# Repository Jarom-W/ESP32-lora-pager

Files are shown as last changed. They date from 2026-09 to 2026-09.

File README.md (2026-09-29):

# ESP32-lora-pager
Source code and supporting files for the ESP32 LoRa powered paging device

LoRa_Enclosure_Design_Pack_Prototype -> The 3D printed prototype case and all related files.

firmware.ino -> Source code firmware written in the Arduino IDE

pager.kicad_pcb -> KiCad PCB file

pager.kicad_pro -> KiCad Project file

pager.kicad_sch -> KiCad PCB schematic

pager_rev1_gerbers.zip -> Gerbers for ordering PCB from a factory

print.pdf -> Printed render of the final PCB.

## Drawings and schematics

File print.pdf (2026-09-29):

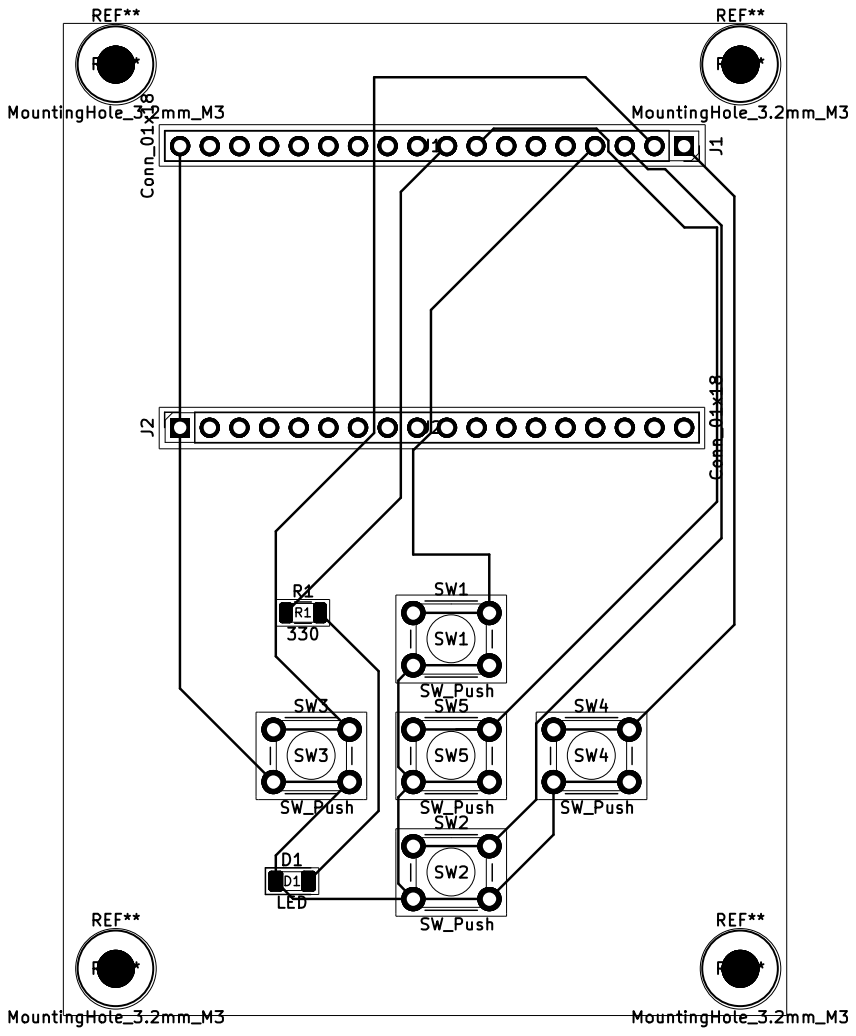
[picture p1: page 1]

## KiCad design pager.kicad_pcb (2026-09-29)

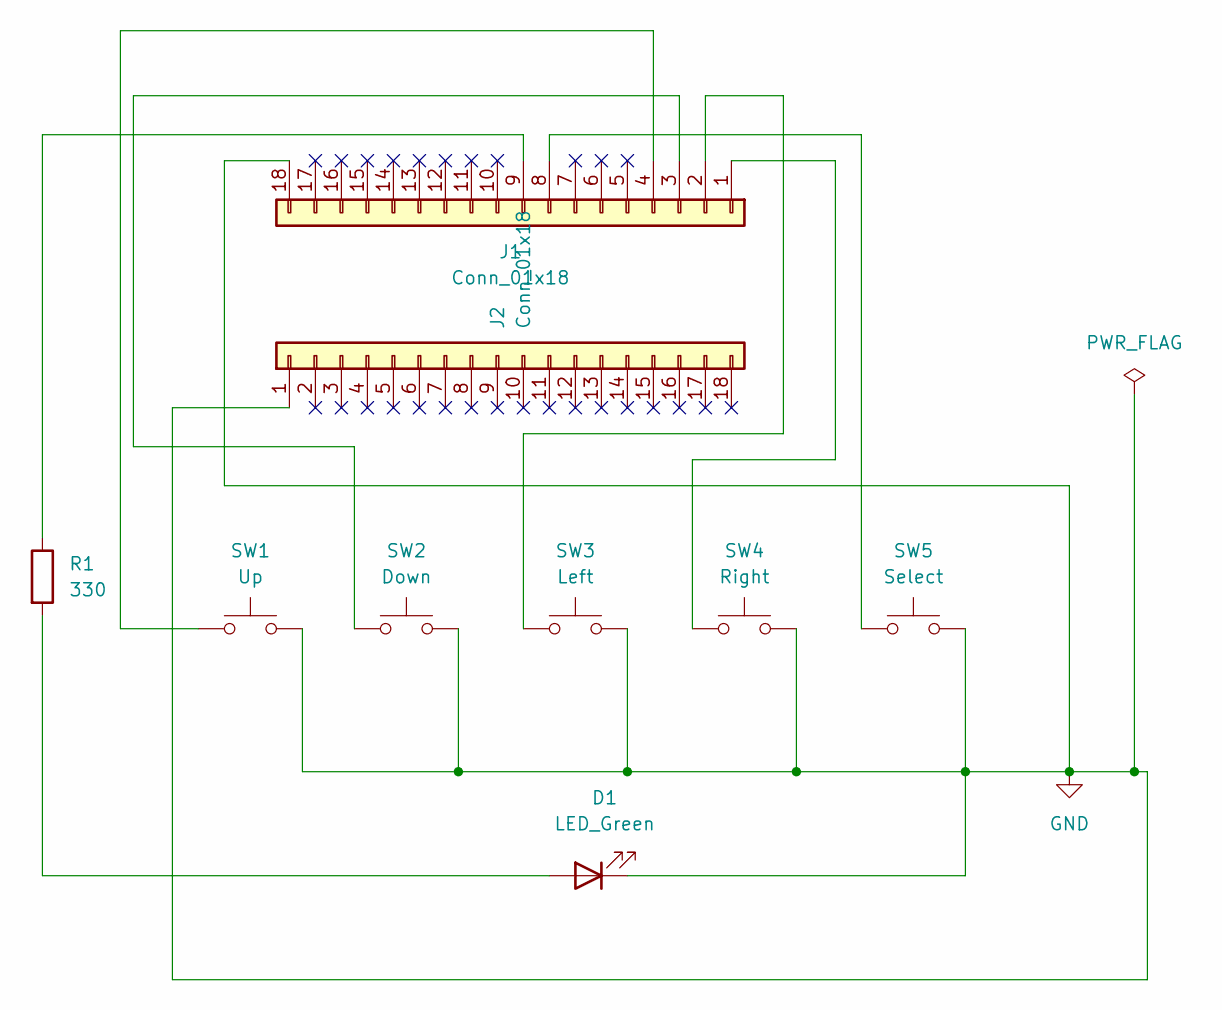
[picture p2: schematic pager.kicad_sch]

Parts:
D1: LED_Green; LED_D5.0mm
J1, J2: Conn_01x18; PinSocket_1x18_P2.54mm_Vertical
R1: 330; R_Axial_DIN0207_L6.3mm_D2.5mm_P7.62mm_Horizontal
SW1: Up; SW_PUSH_6mm
SW2: Down; SW_PUSH_6mm
SW3: Left; SW_PUSH_6mm
SW4: Right; SW_PUSH_6mm
SW5: Select; SW_PUSH_6mm

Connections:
GND: D1.1 (K), J1.18, J2.1, SW1.2, SW2.2, SW3.2, SW4.2, SW5.2
unnamed: D1.2 (A), R1.2
unnamed: J1.1, SW4.1
unnamed: J1.2, SW3.1
unnamed: J1.3, SW2.1
unnamed: J1.4, SW1.1
unnamed: J1.8, SW5.1
unnamed: J1.9, R1.1

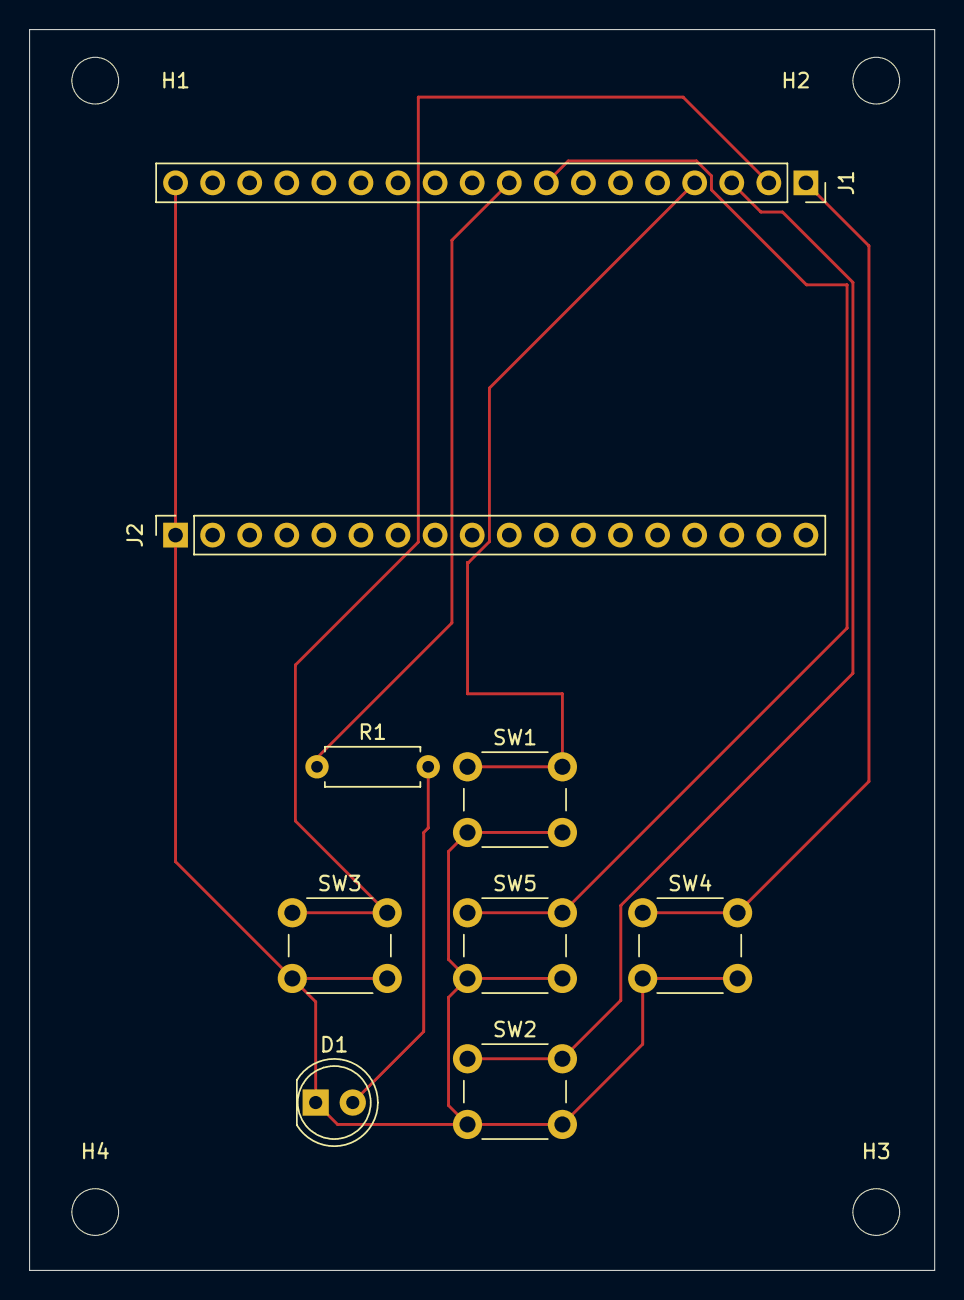
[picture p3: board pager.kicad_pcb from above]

Board: 2 copper layers, 62.0 x 85.0 mm, 13 parts (0 on the bottom side), 8 nets.

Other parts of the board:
H1, H2, H3, H4: MountingHole_3.2mm_M3

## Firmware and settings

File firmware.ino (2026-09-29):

/*
  HeltecPager 1.2 - single-file group text pager for Heltec WiFi LoRa 32 V3.
  Flash this SAME sketch onto every device; Settings > Name personalizes it.

  ARDUINO SETUP
    Board package: esp32 by Espressif Systems
    Board: Heltec WiFi LoRa 32(V3) (ESP32-S3, not V2 or V4)
    USB CDC On Boot: Disabled if offered (onboard CP210x USB-UART).
    Core 2.0.17 sets this automatically for the V3; no menu change needed.
    Libraries: RadioLib, Adafruit SSD1306, Adafruit GFX Library
               (accept their dependencies, including Adafruit BusIO)
    Serial Monitor: 115200 baud, Newline

  VALIDATION
    Compiled with esp32 core 2.0.17, RadioLib 7.1.2, Adafruit SSD1306 2.5.17,
    Adafruit GFX Library 1.12.6, Adafruit BusIO 1.17.4.
    Packet parser passed roundtrip, boundary and 100,000 malformed-input tests
    under AddressSanitizer/UndefinedBehaviorSanitizer (leak check disabled).
    Not tested on physical hardware; confirm operation on two boards first.

  EXTERNAL WIRING - GPIO numbers, NOT header positions
    Up -> GPIO4       Down -> GPIO5       Left -> GPIO6
    Right -> GPIO7    Select -> GPIO38
    Each normally-open button connects its GPIO to GND when pressed.
    Internal pull-ups enabled. No button connects to 3.3V or 5V.
    GPIO39 -> 330-ohm resistor -> LED anode (+); LED cathode (-) -> GND.
    Onboard GPIO35 user LED mirrors unread status; orange charge LED untouched.
    Attach the matching antenna before use. Disconnect power while wiring.

  INTERNAL V3 CONNECTIONS (already wired on board)
    OLED: SDA17, SCL18, reset21; Vext36 active LOW
    SX1262: SCK9, MISO11, MOSI10, CS8, DIO1=14, reset12, BUSY13
    TCXO 1.8V, DIO2 RF switch control

  CONTROLS
    Menus: Up/Down selects, Select opens, Left returns.
    Keyboard: arrows move, Select types. '_'=space, '<'=delete, '>'=done.
    Hold Select 700ms to toggle upper/lower case in keyboard.
    Hold Left 700ms to leave keyboard (message draft retained in RAM).
    Send confirmation: Select sends; Left edits.
    Reader: Up/Down scroll; Left returns; Select opens Quick messages.
    Tap Right on Home to open newest unread message.
    New messages open automatically ONLY from Home; remain unread until an
    explicit open/Select. Editing and menu state are never overwritten.

  RADIO / LIMITS
    Direct group broadcast; no mesh, gateway, encryption, authentication or ACK.
    "Transmitted" means local TX completed, NOT delivery confirmed.
    Same channel and firmware required. Names are labels, not trusted identity.
    Max name 12 printable ASCII characters; text 120; inbox holds latest 20.
    Presets: 903/909/915/921/927 MHz; default 915; BW500kHz/SF12/CR4:8,
    20dBm, sync0x12, CRC on, explicit header, 16-symbol preamble.
    Boosted RX gain enabled. All pagers MUST run this radio profile; versions
    1.0/1.1 cannot receive this profile. Existing names/inbox/channel retained.
    Higher power and longer airtime increase energy per message; boosted RX
    also increases listening current. No guaranteed distance multiplier.
    Packet airtime determines TX timeout and busy-channel retry spacing.
    Typical airtime is about 0.5-2 seconds; backoff adds further delay.
    500kHz bandwidth retained for this fixed-channel US-band design; these
    settings alone do not establish FCC compliance. /status shows RF settings
    and the last valid incoming packet RSSI/SNR for manual range tests.
    These are experimental US-band settings, NOT a certification or compliance
    guarantee. Verify your exact board, antenna and permitted operating profile.
    Do not use this build on 433/868-only hardware or outside applicable regions.
    Always-on RX; OLED blanks after 60s. No deep sleep. Not an emergency pager.
    Bounded random backoff + LoRa activity detection; hidden-node losses remain.
    Incoming packets are strictly length/version checked, then deduplicated.
    Inbox is saved to NVS after a 2-second quiet period (recent entries can be
    lost if power is removed immediately). Name/channel saved on explicit change.
    Inbox times are receiver uptime with boot ID; there is no real-time clock.

  BATTERY (Heltec V3.2, standard 4.2V-full single-cell LiPo)
    Built-in divider: GPIO1 ADC, GPIO37 enable HIGH on V3.2.
    Older V3 revisions may require LOW: change BATTERY_ENABLE_LEVEL below.
    No external battery-sense wiring. Home shows icon and estimated percentage;
    Settings > Battery shows voltage. /battery prints diagnostics.
    Samples every 10 seconds, averaging 16 readings and smoothing between reads.
    Sampling pauses during queued/TX activity and for 2 seconds after TX.
    Percentage is a generic voltage estimate, NOT a measured fuel gauge.
    USB/charging changes readings; assess remaining charge with USB unplugged.
    Voltage alone cannot reliably detect charging or battery presence.
    Low warning below 3.50V for 3 samples; re-arms above 3.65V.
    No automatic shutdown; radio continues listening. Capacity (1000mAh, etc.)
    does not change the voltage curve. BATTERY_CALIBRATION can correct readings
    against a multimeter: new factor = old factor * measured / displayed.

  SERIAL COMMANDS (newline terminated)
    /help /battery /status /name Amber /channel 3 /send Hello /inbox /read 1 /demo
    /up /down /left /right /ok /case /back
    /channel uses 1..5; /demo creates a LOCAL simulated incoming message.
    Serial control permits testing before buttons are wired.

  Primary pin reference:
  https://github.com/espressif/arduino-esp32/blob/master/variants/heltec_wifi_lora_32_V3/pins_arduino.h
*/
#include <Arduino.h>
#include <Wire.h>
#include <SPI.h>
#include <Preferences.h>
#include <Adafruit_GFX.h>
#include <Adafruit_SSD1306.h>
#include <RadioLib.h>
#include <esp_system.h>
#include <ctype.h>
#include <stddef.h>

#if !defined(CONFIG_IDF_TARGET_ESP32S3)
#error "Select Heltec WiFi LoRa 32(V3), an ESP32-S3 board."
#endif

constexpr uint8_t PIN_UP=4, PIN_DOWN=5, PIN_LEFT=6, PIN_RIGHT=7, PIN_OK=38;
constexpr uint8_t PIN_ALERT=39, PIN_USER_LED=35;
constexpr uint8_t PIN_OLED_SDA=17, PIN_OLED_SCL=18, PIN_OLED_RST=21, PIN_VEXT=36;
constexpr uint8_t PIN_BATTERY_ADC=1, PIN_BATTERY_ENABLE=37;
constexpr uint8_t BATTERY_ENABLE_LEVEL=HIGH; // V3.2; older V3 may use LOW.
constexpr float BATTERY_DIVIDER=4.9f, BATTERY_CALIBRATION=1.0f;
constexpr uint32_t BATTERY_INTERVAL_MS=10000;
bool batteryValid=false, batterySampling=false, batteryLow=false;
bool batteryWarningPending=false, batteryHasRead=false, batteryTxSeen=false;
float batteryVolts=0.0f, batteryRawVolts=0.0f;
uint8_t batteryPercent=0, batterySamples=0, batteryLowCount=0;
uint32_t batterySumMv=0, batteryLastRead=0, batteryNextSample=0, batteryLastTx=0;

constexpr size_t NAME_MAX_LEN=12, TEXT_MAX_LEN=120, INBOX_MAX=20, HEADER_LEN=22;
constexpr size_t PACKET_MAX=HEADER_LEN+NAME_MAX_LEN+TEXT_MAX_LEN;
// Shared long-range profile. Keep identical on every pager.
constexpr float RADIO_BW_KHZ=500.0f;
constexpr uint8_t RADIO_SF=12, RADIO_CR=8;
constexpr int8_t RADIO_TX_DBM=20;
constexpr uint16_t RADIO_PREAMBLE=16;
constexpr uint32_t SEND_GAP_MS=5000;
uint32_t txTimeoutMs=6000, maxPacketAirMs=2000;
bool haveLinkSample=false;
float lastRxRssi=0.0f, lastRxSnr=0.0f;
uint32_t lastRxAt=0;
constexpr uint8_t CHANNEL_COUNT=5;
const float CHANNEL_MHZ[CHANNEL_COUNT]={903.0f,909.0f,915.0f,921.0f,927.0f};
const char *QUICK[]={"Come here please.","On my way.","Where are you?","I am home.",
                     "Please call me.","Yes.","No.","Thank you!"};
constexpr uint8_t QUICK_COUNT=sizeof(QUICK)/sizeof(QUICK[0]);
const char KEYBOARD[]="ABCDEFGHIJKLMNOPQRSTUVWXYZ0123456789_.<>";
static_assert(sizeof(KEYBOARD)-1 == 40, "Keyboard must contain 40 keys");

Adafruit_SSD1306 oled(128,64,&Wire,-1,100000,100000);
SX1262 radio = new Module(8,14,12,13);
Preferences prefs;
bool prefsReady=false, oledReady=false, oledSleeping=false, radioReady=false;
int16_t lastRadioError=0;
volatile bool radioIRQ=false;
uint64_t deviceId=0;
uint32_t bootId=0, sequenceNumber=0;
char deviceName[NAME_MAX_LEN+1]={0};
uint8_t channelIndex=2;

struct Message {
  uint64_t sender;
  uint32_t senderBoot, sequence, receivedBoot, receivedSeconds;
  int16_t rssi;
  uint8_t unread;
  char name[NAME_MAX_LEN+1];
  char text[TEXT_MAX_LEN+1];
};
// Explicit declarations keep Arduino auto-prototypes after the Message type.
bool decodePacket(const uint8_t *p, size_t len, Message &m);
void acceptMessage(Message &m);

struct InboxStore {
  uint32_t magic;
  uint16_t version, count;
  Message messages[INBOX_MAX];
};
InboxStore inbox={};
bool inboxDirty=false;
uint32_t inboxChangedAt=0;
struct Seen { uint64_t sender; uint32_t boot, sequence; };
Seen seen[64]={};
uint8_t seenNext=0;

// Use int UI state so Arduino's generated function prototypes require no custom types.
enum { HOME, INBOX, READER, EDIT_TEXT, EDIT_NAME, QUICK_MENU, SETTINGS,
       CHANNEL_MENU, CONFIRM_SEND, ABOUT, CLEAR_CONFIRM, BATTERY_VIEW };
enum { UP, DOWN, LEFT, RIGHT, SELECT };
int view=HOME, homeSelection=0, inboxSelection=0, quickSelection=0;
int settingsSelection=0, channelSelection=2, keyboardSelection=0, readerLine=0;
bool lowercase=false;
char draft[TEXT_MAX_LEN+1]={0}, editedName[NAME_MAX_LEN+1]={0};
Message reading={}; // Copy keeps reader stable when a new message shifts inbox.
uint32_t lastInteraction=0, lastDraw=0;
bool drawNeeded=true;
char notice[22]={0};
uint32_t noticeUntil=0;

struct Button {
  explicit Button(uint8_t p) : pin(p) {}
  uint8_t pin;
  bool raw=false, stable=false, held=false;
  uint32_t changed=0, pressed=0;
};
Button buttons[5]={Button(PIN_UP),Button(PIN_DOWN),Button(PIN_LEFT),Button(PIN_RIGHT),Button(PIN_OK)};

uint8_t txBuffer[PACKET_MAX];
size_t txLength=0;
bool txQueued=false, txActive=false;
uint8_t busyAttempts=0;
uint32_t txDue=0, txStarted=0, lastSendAt=0;
bool haveSent=false;
char txText[TEXT_MAX_LEN+1]={0};
char serialLine[180]={0};
size_t serialLength=0;
bool serialOverflow=false;

void IRAM_ATTR onRadioIRQ() { radioIRQ=true; }

void copyText(char *out, size_t size, const char *in) {
  if (!size) return;
  size_t n=strnlen(in,size-1);
  memcpy(out,in,n); out[n]=0;
}
bool printable(const char *s, size_t n) {
  for(size_t i=0;i<n;++i) if((uint8_t)s[i]<32 || (uint8_t)s[i]>126) return false;
  return true;
}
bool hasNonSpace(const char *s) {
  while(*s) { if(*s!=' ') return true; ++s; } return false;
}
void put32(uint8_t *p,uint32_t v) { for(int i=0;i<4;++i) p[i]=(v>>(8*i))&255; }
uint32_t get32(const uint8_t *p) {
  uint32_t v=0; for(int i=0;i<4;++i) v|=((uint32_t)p[i])<<(8*i); return v;
}
void put64(uint8_t *p,uint64_t v) { for(int i=0;i<8;++i) p[i]=(v>>(8*i))&255; }
uint64_t get64(const uint8_t *p) {
  uint64_t v=0; for(int i=0;i<8;++i) v|=((uint64_t)p[i])<<(8*i); return v;
}
size_t makePacket(uint8_t *out,const char *text) {
  size_t nl=strlen(deviceName), tl=strlen(text);
  if(!nl || nl>NAME_MAX_LEN || !tl || tl>TEXT_MAX_LEN) return 0;
  out[0]='P'; out[1]='G'; out[2]=1; out[3]=1;
  put64(out+4,deviceId); put32(out+12,bootId); put32(out+16,++sequenceNumber);
  out[20]=(uint8_t)nl; out[21]=(uint8_t)tl;
  memcpy(out+HEADER_LEN,deviceName,nl); memcpy(out+HEADER_LEN+nl,text,tl);
  return HEADER_LEN+nl+tl;
}
bool decodePacket(const uint8_t *p,size_t len,Message &m) {
  if(len<HEADER_LEN || len>PACKET_MAX) return false;
  if(p[0]!='P' || p[1]!='G' || p[2]!=1 || p[3]!=1) return false;
  size_t nl=p[20],tl=p[21];
  if(!nl || nl>NAME_MAX_LEN || !tl || tl>TEXT_MAX_LEN || len!=HEADER_LEN+nl+tl) return false;
  if(!printable((const char*)p+HEADER_LEN,nl+tl)) return false;
  memset(&m,0,sizeof(m));
  m.sender=get64(p+4); m.senderBoot=get32(p+12); m.sequence=get32(p+16);
  memcpy(m.name,p+HEADER_LEN,nl); memcpy(m.text,p+HEADER_LEN+nl,tl);
  return hasNonSpace(m.name) && hasNonSpace(m.text);
}

uint8_t unreadCount() {
  uint8_t n=0; for(unsigned i=0;i<inbox.count;++i) if(inbox.messages[i].unread) ++n;
  return n;
}
void updateLED() {
  bool on=unreadCount()>0;
  digitalWrite(PIN_ALERT,on); digitalWrite(PIN_USER_LED,on);
}
void wakeDisplay() {
  lastInteraction=millis();
  if(oledReady && oledSleeping) { oled.ssd1306_command(SSD1306_DISPLAYON); oledSleeping=false; }
  drawNeeded=true;
}
void tell(const char *text,uint32_t duration=2500) {
  copyText(notice,sizeof(notice),text); noticeUntil=millis()+duration;
  Serial.println(text); wakeDisplay();
}
// Piecewise approximation for a typical 1S LiPo, under a light load.
uint8_t batteryPercentForVoltage(float v) {
  const float volts[]={3.30f,3.50f,3.60f,3.70f,3.75f,3.80f,3.85f,3.90f,4.00f,4.10f,4.20f};
  const uint8_t pct[]={0,5,10,20,30,40,50,60,75,90,100};
  if(!isfinite(v) || v<=volts[0]) return 0;
  for(unsigned i=1;i<sizeof(pct);++i) {
    if(v<=volts[i]) return (uint8_t)(pct[i-1]+(v-volts[i-1]) *
      (pct[i]-pct[i-1])/(volts[i]-volts[i-1])+0.5f);
  }
  return 100;
}
void stopBatterySampling() {
  digitalWrite(PIN_BATTERY_ENABLE,BATTERY_ENABLE_LEVEL==HIGH?LOW:HIGH);
  batterySampling=false;
}
void initializeBattery() {
  digitalWrite(PIN_BATTERY_ENABLE,BATTERY_ENABLE_LEVEL==HIGH?LOW:HIGH);
  pinMode(PIN_BATTERY_ENABLE,OUTPUT);
  pinMode(PIN_BATTERY_ADC,INPUT);
  analogReadResolution(12);
  analogSetPinAttenuation(PIN_BATTERY_ADC,ADC_2_5db);
}
void recordBatteryVoltage(float v) {
  batteryRawVolts=v;
  if(!isfinite(v) || v<2.5f || v>4.45f) {
    batteryValid=false; batteryLowCount=0; batteryWarningPending=false;
    drawNeeded=true; return;
  }
  batteryVolts=batteryValid ? batteryVolts+0.25f*(v-batteryVolts) : v;
  batteryValid=true;
  batteryPercent=batteryPercentForVoltage(batteryVolts);
  // Raw averaged voltage makes the alert responsive even while UI is smoothed.
  if(v<=3.50f) {
    if(batteryLowCount<3) ++batteryLowCount;
    if(batteryLowCount>=3 && !batteryLow) {
      batteryLow=true; batteryWarningPending=true;
    }
  } else {
    batteryLowCount=0;
    if(v>=3.65f) { batteryLow=false; batteryWarningPending=false; }
  }
  drawNeeded=true; // Does not wake an idle display on routine measurements.
}
void serviceBattery() {
  uint32_t now=millis();
  if(txActive || txQueued || radioIRQ ||
     (batteryTxSeen && (uint32_t)(now-batteryLastTx)<2000)) {
    if(batterySampling) stopBatterySampling();
    return;
  }
  if(batteryWarningPending && (!notice[0] || (int32_t)(now-noticeUntil)>=0)) {
    batteryWarningPending=false; tell("Battery low: recharge",5000);
  }
  if(!batterySampling) {
    if(batteryHasRead && (uint32_t)(now-batteryLastRead)<BATTERY_INTERVAL_MS) return;
    digitalWrite(PIN_BATTERY_ENABLE,BATTERY_ENABLE_LEVEL);
    batterySampling=true; batterySamples=0; batterySumMv=0;
    batteryNextSample=now+20; // Divider settling; no blocking delay.
    return;
  }
  if((int32_t)(now-batteryNextSample)<0) return;
  batterySumMv+=analogReadMilliVolts(PIN_BATTERY_ADC);
  batteryNextSample=now+3;
  if(++batterySamples<16) return;
  stopBatterySampling(); batteryHasRead=true; batteryLastRead=now;
  recordBatteryVoltage((batterySumMv/16.0f)*0.001f*BATTERY_DIVIDER*BATTERY_CALIBRATION);
}
void printBattery() {
  if(batteryValid) Serial.printf("Battery: ~%u%%, filtered %.3f V, latest %.3f V%s; age %lu s\n",
    batteryPercent,batteryVolts,batteryRawVolts,batteryLow?" LOW":"",
    (unsigned long)((millis()-batteryLastRead)/1000));
  else Serial.printf("Battery: %s; latest %.3f V\n",
    batteryHasRead?"reading unavailable":"waiting for first sample",batteryRawVolts);
  Serial.println("Voltage estimate only; USB/charging affects it. V3.2 GPIO37 enable=HIGH.");
}
void drawBatteryIcon(int x,int y) {
  oled.drawRect(x,y,19,8,SSD1306_WHITE);
  oled.fillRect(x+19,y+2,2,4,SSD1306_WHITE);
  if(!batteryValid) { oled.setCursor(x+6,y); oled.print('?'); return; }
  if(batteryLow) { oled.setCursor(x+6,y); oled.print('!'); return; }
  unsigned bars=(batteryPercent+19)/20;
  for(unsigned i=0;i<bars;++i) oled.fillRect(x+2+i*3,y+2,2,4,SSD1306_WHITE);
}

void dirtyInbox() { inboxDirty=true; inboxChangedAt=millis(); }
void saveSettings() {
  if(!prefsReady) return;
  if(!prefs.putString("name",deviceName) || !prefs.putUChar("channel",channelIndex))
    Serial.println("WARNING: could not save settings.");
}
void saveInbox() {
  if(!inboxDirty) return;
  inboxDirty=false;
  if(prefsReady && prefs.putBytes("inbox",&inbox,sizeof(inbox))!=sizeof(inbox))
    Serial.println("WARNING: inbox save failed.");
}
void remember(uint64_t id,uint32_t boot,uint32_t seq) {
  seen[seenNext]={id,boot,seq}; seenNext=(seenNext+1)%64;
}
bool alreadySeen(uint64_t id,uint32_t boot,uint32_t seq) {
  for(const auto &s:seen) if(s.sender==id && s.boot==boot && s.sequence==seq) return true;
  return false;
}
void loadStorage() {
  inbox.magic=0x50414731; inbox.version=1;
  prefsReady=prefs.begin("heltecpager",false);
  if(!prefsReady) { Serial.println("NVS unavailable: settings/inbox volatile."); return; }
  String saved=prefs.getString("name",deviceName);
  if(saved.length()>0 && saved.length()<=NAME_MAX_LEN &&
     printable(saved.c_str(),saved.length()) && hasNonSpace(saved.c_str()))
    copyText(deviceName,sizeof(deviceName),saved.c_str());
  channelIndex=prefs.getUChar("channel",2);
  if(channelIndex>=CHANNEL_COUNT) channelIndex=2;
  if(prefs.getBytesLength("inbox")==sizeof(inbox)) {
    if(prefs.getBytes("inbox",&inbox,sizeof(inbox))!=sizeof(inbox) ||
       inbox.magic!=0x50414731 || inbox.version!=1 || inbox.count>INBOX_MAX) inbox.count=0;
    for(unsigned i=0;i<inbox.count;++i) {
      auto &m=inbox.messages[i];
      if(strnlen(m.name,sizeof(m.name))>NAME_MAX_LEN || strnlen(m.text,sizeof(m.text))>TEXT_MAX_LEN ||
         !printable(m.name,strnlen(m.name,sizeof(m.name))) ||
         !printable(m.text,strnlen(m.text,sizeof(m.text))) || m.unread>1) { inbox.count=0; break; }
    }
  }
  inbox.magic=0x50414731; inbox.version=1;
  for(unsigned i=0;i<inbox.count;++i)
    remember(inbox.messages[i].sender,inbox.messages[i].senderBoot,inbox.messages[i].sequence);
}
void markReadingRead() {
  for(unsigned i=0;i<inbox.count;++i) {
    auto &m=inbox.messages[i];
    if(m.sender==reading.sender && m.senderBoot==reading.senderBoot && m.sequence==reading.sequence) {
      if(m.unread) { m.unread=0; dirtyInbox(); }
      break;
    }
  }
  reading.unread=0; updateLED(); drawNeeded=true;
}
void openMessage(int index) {
  if(index<0 || index>=inbox.count) return;
  reading=inbox.messages[index]; readerLine=0; view=READER; markReadingRead(); wakeDisplay();
}
void acceptMessage(Message &m) {
  if(alreadySeen(m.sender,m.senderBoot,m.sequence)) return;
  remember(m.sender,m.senderBoot,m.sequence);
  m.receivedBoot=bootId; m.receivedSeconds=millis()/1000; m.unread=1;
  unsigned shift=inbox.count<INBOX_MAX ? inbox.count : INBOX_MAX-1;
  memmove(&inbox.messages[1],&inbox.messages[0],shift*sizeof(Message));
  inbox.messages[0]=m;
  if(inbox.count<INBOX_MAX) ++inbox.count;
  if(view==INBOX && inbox.count>1 && inboxSelection<(int)inbox.count-1) ++inboxSelection;
  dirtyInbox(); updateLED();
  Serial.printf("RX %s: %s [RSSI %d]\n",m.name,m.text,m.rssi);
  if(view==HOME) { reading=m; readerLine=0; view=READER; }
  else { snprintf(notice,sizeof(notice),"New: %.12s",m.name); noticeUntil=millis()+2500; }
  wakeDisplay();
}

void startListening() {
  radioIRQ=false;
  int16_t status=radio.startReceive();
  if(status!=RADIOLIB_ERR_NONE) {
    radioReady=false; lastRadioError=status;
    Serial.printf("RX start error %d; Settings > Retry radio\n",status);
    drawNeeded=true;
  }
}
void initializeRadio() {
  radioReady=false; radioIRQ=false;
  int16_t s=radio.begin(CHANNEL_MHZ[channelIndex],RADIO_BW_KHZ,RADIO_SF,RADIO_CR,
                        0x12,RADIO_TX_DBM,RADIO_PREAMBLE,1.8,false);
  if(s==RADIOLIB_ERR_NONE) s=radio.setDio2AsRfSwitch(true);
  if(s==RADIOLIB_ERR_NONE) s=radio.setCRC(2);
  if(s==RADIOLIB_ERR_NONE) s=radio.setRxBoostedGainMode(true);
  lastRadioError=s;
  if(s!=RADIOLIB_ERR_NONE) { Serial.printf("Radio init error %d\n",s); drawNeeded=true; return; }
  maxPacketAirMs=(radio.getTimeOnAir(PACKET_MAX)+999UL)/1000UL;
  radio.setDio1Action(onRadioIRQ);
  radioReady=true; startListening();
  Serial.printf("Radio %s: %.1f MHz, BW%.0f SF%u CR4:%u, %ddBm, preamble %u, boosted RX\n",
                radioReady?"ready":"failed",CHANNEL_MHZ[channelIndex],RADIO_BW_KHZ,
                RADIO_SF,RADIO_CR,RADIO_TX_DBM,RADIO_PREAMBLE);
  drawNeeded=true;
}
void queueMessage(const char *text) {
  size_t len=strlen(text);
  if(!len || len>TEXT_MAX_LEN || !printable(text,len) || !hasNonSpace(text)) {
    tell("Use 1-120 ASCII chars"); return;
  }
  if(!radioReady) { tell("Radio unavailable"); return; }
  if(txQueued || txActive) { tell("Already sending"); return; }
  if(haveSent && (uint32_t)(millis()-lastSendAt)<SEND_GAP_MS) { tell("Wait a few seconds"); return; }
  copyText(txText,sizeof(txText),text);
  txLength=makePacket(txBuffer,txText);
  if(!txLength) { tell("Packet build failed"); return; }
  txQueued=true; busyAttempts=0; txDue=millis()+250+(esp_random()%1250);
  tell("Queued for broadcast");
}
void finishTx(bool timedOut) {
  batteryTxSeen=true; batteryLastTx=millis();
  int16_t s=radio.finishTransmit();
  txActive=false;
  if(!timedOut && s==RADIOLIB_ERR_NONE) {
    lastSendAt=millis(); haveSent=true;
    Serial.printf("TX complete: %s (no delivery ACK)\n",txText);
    if(strcmp(draft,txText)==0) draft[0]=0;
    if(view==CONFIRM_SEND) view=HOME;
    tell("Transmitted (no ACK)");
  } else { lastRadioError=timedOut?RADIOLIB_ERR_TX_TIMEOUT:s; tell("TX failed; try again"); }
  startListening();
}
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
void loop() {
  serviceRadio(); pollButtons(); serviceSerial(); serviceBattery();
  uint32_t now=millis();
  if(inboxDirty && !txActive && !txQueued && (uint32_t)(now-inboxChangedAt)>=2000) saveInbox();
  if(notice[0] && (int32_t)(now-noticeUntil)>=0) { notice[0]=0; drawNeeded=true; }
  if(oledReady && !oledSleeping && (uint32_t)(now-lastInteraction)>=60000) {
    oled.ssd1306_command(SSD1306_DISPLAYOFF); oledSleeping=true;
  }
  if(drawNeeded && (uint32_t)(now-lastDraw)>=40) drawUI();
  delay(2);
}
